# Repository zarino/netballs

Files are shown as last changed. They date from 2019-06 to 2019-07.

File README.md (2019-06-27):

# Interesting links about DMX

## General explainers

* [Element14 – DMX Explained](https://www.element14.com/community/groups/open-source-hardware/blog/2017/08/24/dmx-explained-dmx512-and-rs-485-protocol-detail-for-lighting-applications)
* [Sparkfun – Introduction to DMX](https://learn.sparkfun.com/tutorials/introduction-to-dmx/all)
* [Instructables – How to Use DMX512 / RDM With Raspberry Pi](https://www.instructables.com/id/How-to-Use-DMX512-RDM-With-Raspberry-Pi/)
  * …Uses a [Zihatec RS485 HAT for Raspberry Pi](https://www.hwhardsoft.de/english/projects/rs485-shield/)

## DMX interfaces

* [Bitwizard DMX interface board for Raspberry Pi](https://www.bitwizard.nl/shop/DMX-interface-for-Raspberry-pi) – with input and output
* Enttec seem to have cornered the market on USB-to-DMX adaptors – <https://www.enttec.co.uk/product/protocols-gb/dmx512-gb/open-dmx-usb/> – fairly expensive.
* Chap using a Raspberry Pi to control lights via a cheap clone of an Enttec USB-to-DMX interface – <https://www.youtube.com/watch?v=ch0sNUbO9lo>
* A completely DIY DMX interface, using an Arduino – <https://www.instructables.com/id/Build-Your-Own-DMX-Fixture-Arduino/>

## RS485 interfaces

* [Zihatec RS485 HAT for Raspberry Pi](https://www.hwhardsoft.de/english/projects/rs485-shield/)
  * …Which was used in [this Instructables guide](https://www.instructables.com/id/How-to-Use-DMX512-RDM-With-Raspberry-Pi/)
* <https://www.instructables.com/id/DMX-512-to-Serial-Adapter/>

## Raspberry Pi as DMX transmitter/controller ONLY

(Not quite what we’re after – we want Raspberry Pi to _receive_ DMX command over XLR cable.)

* QLC is Linux-based DMX controller software – <https://qlcplus.org/raspberry.html>
* “DiscoHAT” board sending DMX from a Raspberry Pi – <https://www.discohat.com/discohat/>
* Another example, using a Velleman USB-to-DMX interface [£61 on Amazon](https://www.amazon.co.uk/Velleman-K8062-Controlled-Interface-multicolored/dp/B000TA79UK) – <https://www.instructables.com/id/Raspberry-Pi-as-a-DMX-light-controller/>
* ["Tinkerkit" Arduino DMX Master Shield at RS Components](https://uk.rs-online.com/web/p/processor-microcontroller-development-kits/7798870/)

## ESP32 as DMX receiver

* [Sparkfun –  Using Artnet DMX and the ESP32 to Drive Pixels](https://learn.sparkfun.com/tutorials/using-artnet-dmx-and-the-esp32-to-drive-pixels)

## Arduino as DMX receiver

* https://www.maxpierson.me/2009/04/29/arduino-dmx-512-io-shield/

# I have no idea what this is all about, but it looks promising

* <https://sites.google.com/site/rpidmx512/>
   * <https://sites.google.com/site/rpidmx512/raspberry-pi-rdm-controller>
   * <https://sites.google.com/site/rpidmx512/raspberry-pi-rdm-responder>
* <https://github.com/vanvught/rpidmx512>

# DMX lighting control software for Mac

* <https://zarino.co.uk/post/udmx-mac/> – uDMX command line utility
* <https://lightkeyapp.com/en/> – free as long as you need fewer than 24 channels

# Raspberry Pi as Wifi access point and client

* <https://www.raspberrypi.org/documentation/configuration/wireless/access-point.md#internet-sharing>
* <https://lb.raspberrypi.org/forums/viewtopic.php?t=211542>
* <http://www.marrold.co.uk/2017/03/using-raspberry-pi-3-as-wifi-client-and.html>
* <https://raspberrypi.stackexchange.com/questions/67601/>

# MQTT

* <https://github.com/DoESLiverpool/somebody-should/wiki/MQTT-services>

# Power control for Raspberry Pi

* £6.50 OnOff SHIM – from [Pimoroni](https://shop.pimoroni.com/products/onoff-shim) or [The PiHut](https://thepihut.com/collections/raspberry-pi-hats/products/onoff-shim)
* £15 [Pi Supply Switch](https://uk.pi-supply.com/products/pi-supply-raspberry-pi-power-switch)

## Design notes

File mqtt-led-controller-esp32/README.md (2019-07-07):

# mqtt-led-controller-esp32

This MicroPython code tells the ESP32 how to:

1. Connect to the `netball-hub-wifi` network being broadcast by the [netball-hub](../netball-hub) Raspberry Pi.
2. Listen for MQTT messages on the `netball/…` topic, eg: `netball/red 255`
3. Translate those MQTT messages into control signals for the connected SK6812 LEDs.

## How to use this

### Install the serial driver onto your computer

Download and install the [CP210x USB-to-UART Bridge VCP serial driver](https://www.silabs.com/products/development-tools/software/usb-to-uart-bridge-vcp-drivers) if you don’t already have it.

If you’re on a Mac, you’ll need to “Allow” the extension in System Preferences – your Mac will show you how. You won’t need to restart your Mac after the installation.

### Test communication with the board

The Arduino IDE is a quick way to test you can communicate with your board. You will need to [follow the first section of this guide](https://randomnerdtutorials.com/installing-the-esp32-board-in-arduino-ide-mac-and-linux-instructions/) to install the ESP32 boards into the IDE’s Board Manager.

Zarino’s note: The first time I did this, I got an error when I tried to upload the “Wifi Scan” example code from the Arduino IDE to the board, for testing:

    serial.serialutil.SerialException: Could not configure port: (6, 'Device not configured’)

I read a quick fix is to hold down the BOOT button while the code was uploading, and that allowed the code to upload fine. But then I wasn’t getting any serial output. I tried pressing the BOOT and RST buttons, to no avail.

Unplugged and re-plugged the USB cable, and the ESP32 booted up and started writing serial to the Arduino Serial Monitor. Your mileage may vary.

### Flash the MicroPython firmware onto the board

You’ll probably also want to create a virtualenv to store the Python packages we’re about to install:

    cd mqtt-led-controller-esp32
    virtualenv .
    . bin/activate

Now install the Python packages:

    pip install -r requirements.txt

If you’re using a brand new EPS32, you’ll need to erase its flash memory:

    esptool.py --port /dev/tty.SLAB_USBtoUART erase_flash

Now, [download the latest MicroPython firmware binary for the ESP32](https://micropython.org/download#esp32), and flash it onto the board using this command (remembering to replace `/path/to/esp32-blah-blah.bin` with the path of the firmware binary you just downloaded):

    esptool.py --chip esp32 --port /dev/tty.SLAB_USBtoUART write_flash -z 0x1000 /path/to/esp32-blah-blah.bin

If you encounter any problems at this point, [check out the “Getting started with MicroPython on the ESP32“ tutorial here](https://docs.micropython.org/en/latest/esp32/tutorial/intro.html) for troubleshooting advice.

To test the MicroPython firmware has been correctly installed, open a terminal emulator session to the ESP32. On a Mac, you can do this using `screen`:

    screen /dev/tty.SLAB_USBtoUART 115200

Press the `Return` key a few times, and you should be given a command prompt like `>>>`. If you type some simple Python in here (like `1+1`) you should get an answer (`2`).

You can exit the `screen` session by pressing `ctrl`–`A` then `ctrl`–`\`.

### Upload the `minimalmdns.py` package onto the board

The ESP32 has a very simple filesystem. By default, the Python path expects local packages to be in the `/lib` directory. So we’ll need to create that directory, and then copy our `minimalmdns.py` package into it.

You do both of these things with the `ampy` command, installed as part of the `pip install -r requirements.txt` line you ran earlier.

First create the `/lib` directory on the ESP32:

    ampy --port /dev/tty.SLAB_USBtoUART mkdir /lib

Now copy `minimalmdns.py` into that `/lib` directory:

    ampy --port /dev/tty.SLAB_USBtoUART put vendor/minimalmdns.py /lib/minimalmdns.py

### Upload `main.py` onto the board

The ESP32 will run `/boot.py` on startup (if the file exists) and then `/main.py`.

To upload `main.py` to the ESP32:

    ampy --port /dev/tty.SLAB_USBtoUART put main.py

### Send test MQTT messages

Run commands like this to control the ESP32:

    mosquitto_pub --host netball-hub.local --topic netball/red -m 255

### Open a Python terminal on the ESP32

To open a terminal session on the ESP32:

    screen /dev/tty.SLAB_USBtoUART 115200

Press Enter or `Ctrl`-`C` to get to a Python REPL prompt.

Press `Ctrl`-`A` then `Ctrl`-`\`, then `Y` to exit.

## Useful links

* https://learn.sparkfun.com/tutorials/micropython-programming-tutorial-getting-started-with-the-esp32-thing/all
* https://github.com/dphans/micropython-ide-vscode

* https://github.com/DoESLiverpool/what-does-health-look-like/blob/master/mqtt_neopixel_visualiser/mqtt_neopixel_visualiser.ino
* https://github.com/goatchurchprime/jupyter_micropython_developer_notebooks/blob/master/projects/mqtt2drumneopixel_mdns.ipynb

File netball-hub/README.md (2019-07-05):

# netball-hub

Code relating to the setup of a Raspberry Pi as an MQTT broker and a DMX interface.

## Setting up Raspbian, wifi, and SSH access

Follow the instructions here to get the Pi into a suitable state for provisioning:

<https://zarino.co.uk/post/raspberry-pi-mac-setup/>

Change the Pi’s `hostname` to `netball-hub`, and set up password-less SSH login with `ssh-copy-id`, so that you can SSH right into the Pi with just:

    ssh pi@netball-hub.local

## Provisioning

Install Ansible on your main machine. For example, on a Mac:

    brew install ansible

Or on Ubuntu:

    sudo apt-get install ansible

Then run the provisioner in `ansible-provisioning`:

    cd ansible-provisioning
    ansible-playbook -i inventory.yml playbook.yml

_(Much of the MQTT provisioning has been adapted from instructions at <https://oneguyoneblog.com/2017/06/20/mosquitto-mqtt-node-red-raspberry-pi/>.)_

For now, you’ll need to install the RaspAP wifi access point stuff by hand. SSH into the Pi, then become root, and run the installer:

    ssh pi@netball-hub.local
    sudo su
    wget -q https://git.io/voEUQ -O /tmp/raspap && bash /tmp/raspap
    reboot

Now connect to the Pi’s wifi network:

    SSID      raspi-webgui
    Password  ChangeMe

The RaspAP admin interface should now be accessible at:

    URL       http://netball-hub.local/
    Username  admin
    Password  secret

Visit the [Configure hostspot](http://netball-hub.local/index.php?page=hostapd_conf) page and make the following changes:

* Basic->SSID: `netball-hub-wifi`
* Security->PSK: `bubblino`
* Advanced->Country Code: `United Kingdom`

Press the "Save settings" button, then cross your fingers. The `raspi-webgui` network should disappear, and a new `netball-hub-wifi` should replace it.

The Pi should have access to the wider internet (via its connection as a _client_ to the `DoESLiverpool` wifi network), but it doesn’t seem that devices _connected_ to the Pi’s `netball-hub-wifi` network will get the same internet connection. Annoying.

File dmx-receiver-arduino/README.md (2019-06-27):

# dmx-receiver-arduino

We have a cheap Arduino Uno clone, and a [Conceptinetics CTC-DRA-10-R2 DMX shield](https://www.tindie.com/products/Conceptinetics/dmx-shield-for-arduino-rdm-capable/).

The aim is to have the Uno read incoming DMX commands, on a configurable range of channels, and then send those commands to a connected Raspberry Pi, via [SoftwareSerial](https://www.arduino.cc/en/Reference/SoftwareSerial), since the Arduino can’t send serial comms over USB when the DMX shield is attached.

We’ll use a [YF08E voltage translator](http://www.datasheetcafe.com/yf08e-pdf-datasheet-30695/) to protect the Raspberry Pi’s 3.3V GPIO from the Arduino’s 5V output.

## How to set up the Arduino

You need to install the Conceptinetics DMX Library onto your computer before you can compile the code.

1. Download the DMX library as a `.zip` file from <http://sourceforge.net/projects/dmxlibraryforar>
2. Install the library using one of the methods described at <https://www.arduino.cc/en/Guide/Libraries>.

If the DMX shield is in place on the Arduino Uno, make sure its `EN` jumper is in the "off" position (shown as `EN` with a line above it, ie: "NOT EN") when you are uploading code to the Arduino. The DMX shield communicates with the Arduino over serial, so you must turn the shield off (by setting the `EN` jumper to "off") to re-enable normal serial communication between your computer and the Arduino.

Once you’ve uploaded the code to the Arduino, remember re-activate the shield by turning the `EN` jumper to the "on" position (shown as `EN` without a line above it).

## How to set up the Raspberry Pi

See [../serial-monitor-test-python](../serial-monitor-test-python).

## How to connect the Arduino and the Pi, via the voltage translator

<https://pinout.xyz> will come in useful for identifying the Pi GPIO pins.

* Arduino pin 10 -> Voltage translator B1
* Arduino pin 11 -> Voltage translator B2
* Arduino 5V -> Voltage translator VB
* Arduino GND -> Voltage translator GND

* Raspberry Pi USB -> Arduino USB (for power, and common ground)

* Pi pin 1 -> Voltage translator VA
* Pi pin 8 -> Voltage translator A1
* Pi pin 10 -> Voltage translator A2

* Voltage translator VA -> Voltage translator OE

## Useful links

DMX shield

* https://forum.arduino.cc/index.php?topic=458860.0 – Someone with our exact DMX Shield, discovering that it hogs the Serial RX/TX lines on the Arduino, meaning you can’t use USB Serial input/output when the shield is active.

I2C – Pi as master, Arduino as slave

* https://raspberrypi.stackexchange.com/questions/62206/sending-and-receiving-string-data-between-arduino-and-raspberry-pi-using-the-i2c – Example of using `RPi.GPIO` Python module, to send I2C commands from a Raspberry Pi master to an Arduino slave, and then the Arduino `Wire` library to receive those commands.

I2C – Pi as slave, Arduino as master

* https://raspberrypi.stackexchange.com/questions/76109/raspberry-as-an-i2c-slave – Raspberry Pi as I2C slave
* https://www.raspberrypi.org/forums/viewtopic.php?t=235740 – Raspberry Pi as I2C slave
* https://oroboto.net/2018/10/21/arduino-with-raspberry-pi-i2c-slave/ – Example of using `pigpio` C-library, via the Python bindings, to send I2C commands from an Arduino master to a Raspberry Pi slave.

I2C on a Pi in general

* https://github.com/joan2937/pigpio – `pigpio` C-library, includes Python bindings.
* https://learn.adafruit.com/adafruits-raspberry-pi-lesson-4-gpio-setup/configuring-i2c – Configuring I2C on a Raspberry Pi.
* https://pinout.xyz/pinout/i2c – Pinout diagram showing location of I2C pins on Raspberry Pi.
* https://learn.sparkfun.com/tutorials/raspberry-pi-spi-and-i2c-tutorial/all – Nice clear example of using I2C on a Raspberry Pi (using `smbus` Python library).

I2C on an Arduino in general

* https://github.com/mcauser/i2cdetect – Arduino version of the Pi’s `i2cdetect` utility program, useful for showing I2C addresses of devices connected to the Arduino.

3.3V Pi GPIO vs 5V Arduino GPIO

* https://raspberrypi.stackexchange.com/questions/95430/5v-3-3v-sensors-confusion – Info about the danger of sending 5V signals to the Raspberry Pi’s 3V GPIO.
* https://www.raspberrypi-spy.co.uk/2018/09/using-a-level-shifter-with-the-raspberry-pi-gpio/ – voltage level shifting.

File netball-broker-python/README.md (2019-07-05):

# netball-broker-python

`broker.py` is the script that will eventually run on the Rasbperry Pi, reading (software) serial data from the connected Arduino Uno, and publishing them to its MQTT server.

`serial-debug.py` is a handy command line script for testing the Pi’s software serial connection – it just prints out any data received on the specified serial port.

## Running broker.py as a systemd background process, on boot

Git clone this repo onto the Raspberry Pi, and make sure you’ve installed the Python dependencies:

    cd /home/pi
    git clone https://github.com/zarino/netballs.git
    cd netballs/netball-broker-python/
    pip install -r requirements.txt

Copy the `netball-broker.service` file to the systemd directory:

    sudo cp /home/pi/netballs/netball-broker-python/netball-broker.service /lib/systemd/system/netball-broker.service
    sudo chmod 644 /lib/systemd/system/netball-broker.service

Note: If you’ve checked out the Git repo somewhere _other_ than `/home/pi/netballs` then you’ll need to amend the `ExecStart` line inside `netball-broker.service` to include the correct path to `broker.py`.

Once the `netball-broker.service` file has been copied, you can tell systemd to load it:

    sudo systemctl daemon-reload
    sudo systemctl enable netball-broker

Systemd will start the service at the next boot.

If you want to start the service _right now_, you can:

    sudo systemctl start netball-broker

Other systemd commands work as you’d expect:

    systemctl status netball-broker
    sudo systemctl stop netball-broker

And if you want to test it out by rebooting the Pi:

    sudo reboot

## Tips for debugging

You can publish and monitor MQTT messages using the [mosquitto command line programs](https://mosquitto.org/download/). This comes in handy when you want to send a test message, or you want to see which messages are already being sent.

On a Mac, you can get it via Homebrew:

    brew install mosquitto

Then, to publish a message:

    mosquitto_pub --host netball-hub.local --topic netball/red -m 255

And to monitor all messages:

    mosquitto_sub -v --host netball-hub.local --topic '#'

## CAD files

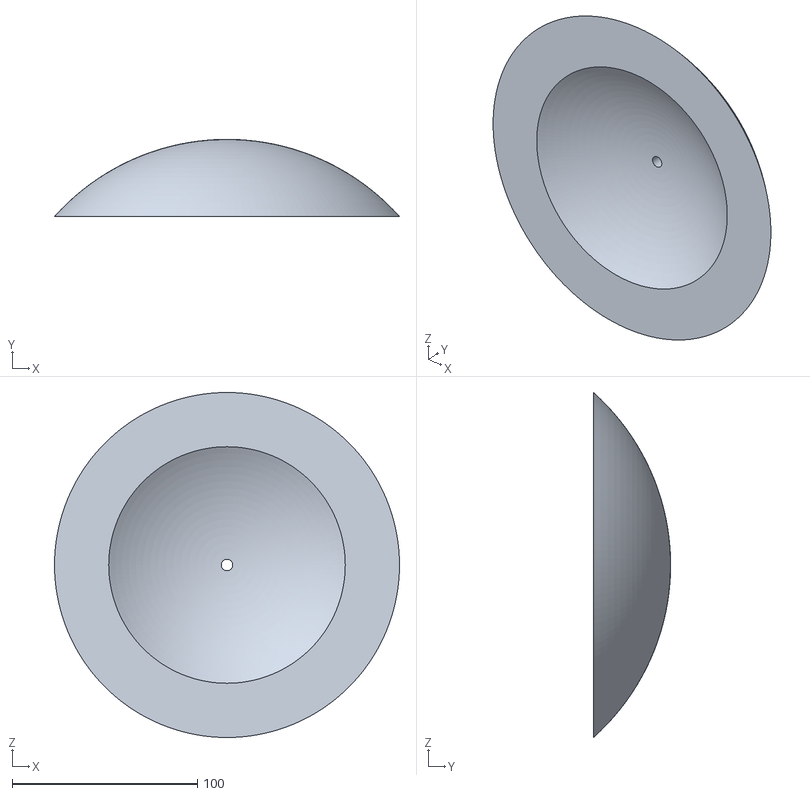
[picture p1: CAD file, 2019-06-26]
netball-3dp-files/netballTop.stl
186.3 x 41.6 x 186.3

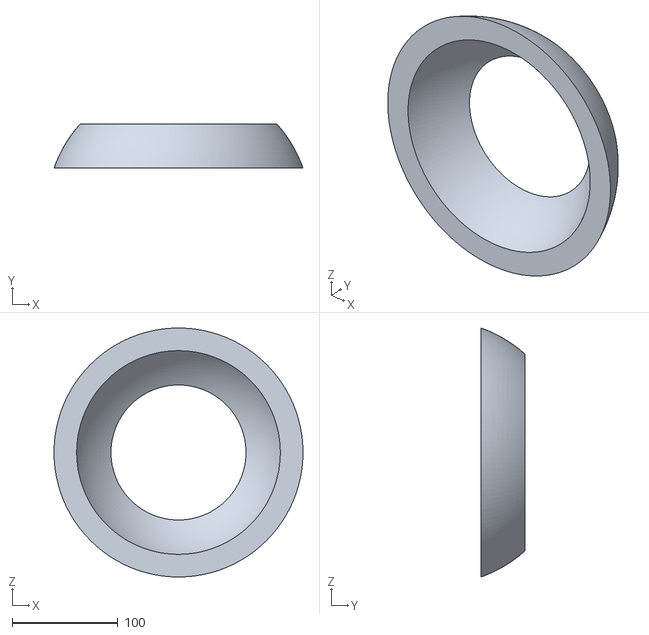
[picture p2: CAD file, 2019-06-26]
netball-3dp-files/netball2ndLayer.stl
235.7 x 41.7 x 235.7

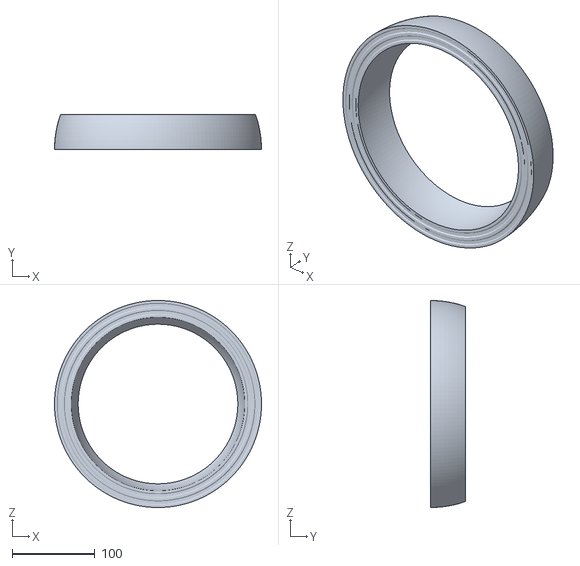
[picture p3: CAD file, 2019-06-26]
netball-3dp-files/netball3rdLayer.stl
250.0 x 41.7 x 250.0

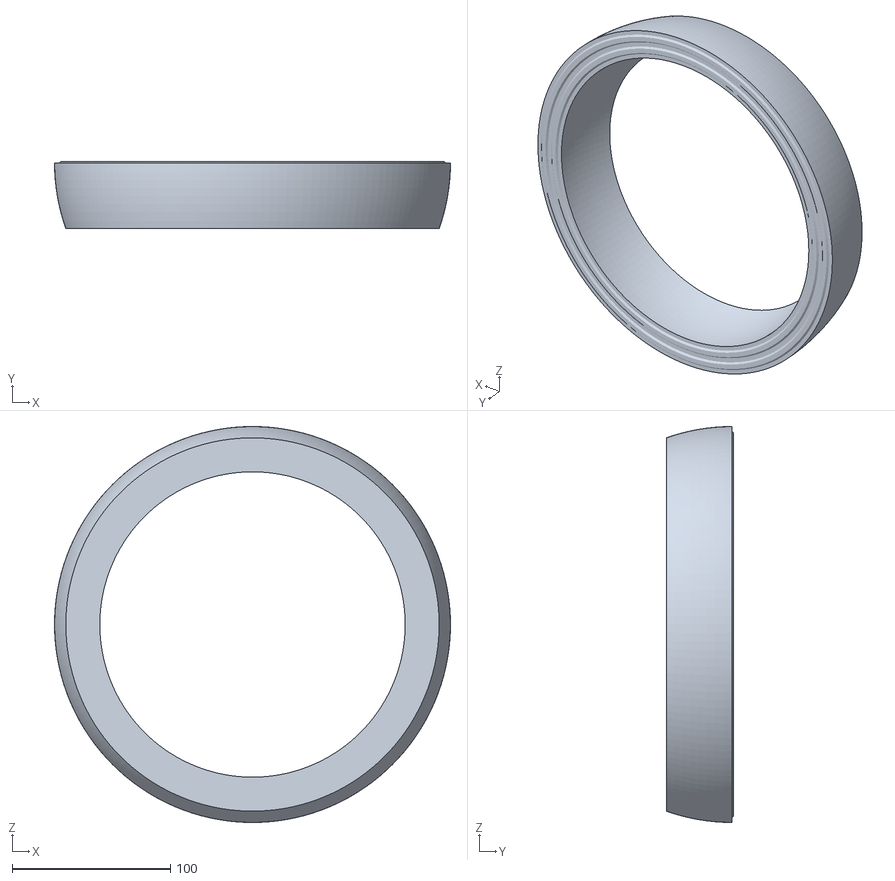
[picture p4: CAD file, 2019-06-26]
netball-3dp-files/netball4thLayer.stl
250.0 x 42.6 x 250.0

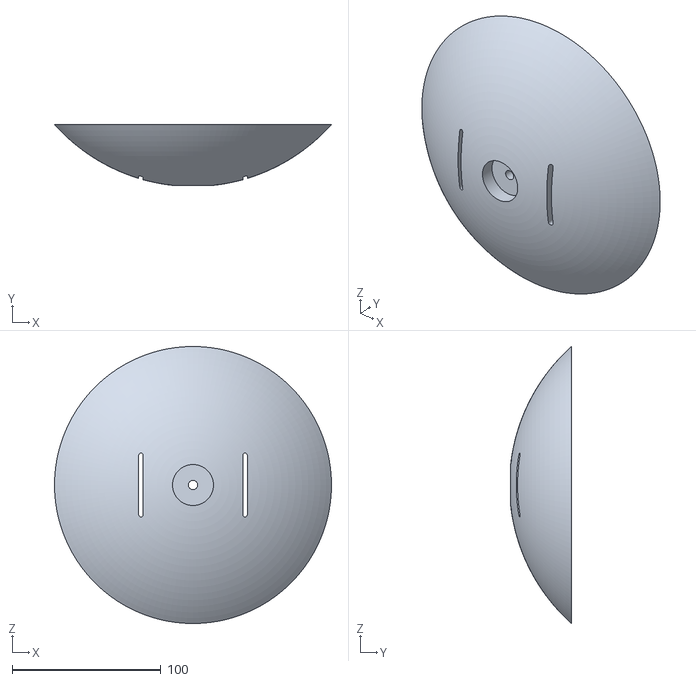
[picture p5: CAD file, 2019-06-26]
netball-3dp-files/netballBase.stl
186.3 x 40.9 x 186.3

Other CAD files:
netball-3dp-files/netball5thLayer.stl

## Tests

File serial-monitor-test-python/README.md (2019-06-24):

# serial-monitor-test-python

Quick Python script for reading and printing serial input.

Useful when combined with an Arduino running the [serial-print-test-arduino](../serial-print-test-arduino) program.

## How to use this

You’ll probably want to create a virtualenv to store the Python library we’re about to install:

    cd serial-monitor-test
    virtualenv .
    . bin/activate

Now install the [`pyserial`](https://pythonhosted.org/pyserial/index.html) library:

    pip install -r requirements.txt

And finally run the script:

    ./monitor.py

Exit the program by typing `ctrl`-`C`.

The script assumes a serial port path of `/dev/ttyUSB0`. If yours is different, supply it as an argument:

    ./monitor.py -p /dev/tty.wchusbserial1410

You can see all options by adding `--help`:

    ./monitor.py --help

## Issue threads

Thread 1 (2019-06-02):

Power

jackie1050, 2019-06-02:
# Powering the ESP32

9v battery
https://docs.zerynth.com/latest/official/board.zerynth.doit_esp32/docs/index.html#power
> Power to the DOIT Esp32 DevKit v1 is supplied via the on-board USB Micro B connector or directly via the “VIN” pin. The power source is selected automatically.
>
> The device can operate on an external supply of 6 to 20 volts. If using more than 12V, the voltage regulator may overheat and damage the device. The recommended range is 7 to 12 volts.

jackie1050, 2019-06-02:
SK6812:
https://cellpacksolutions.co.uk/products/batteries/gp-batteries-gp410lah-18650-rechargeable-battery/
GP Batteries GP410LAH 18650 Rechargeable Battery
Need a battery charger: https://cellpacksolutions.co.uk/products/product-category/battery-chargers/nimh-nicd/
Something to hold 4 in series (3d printed or bought - not a standard AA size)
Switch to disconnect from circuit

zarino, 2019-06-15:
John C has offered us twenty 3.7V 4000mAh Li-ion 18650 batteries.

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

Despite these being 3.7V (rather than 5V) we’ve had one driving a strand test on 60 SK6812 LEDs, at full brightness, and it’s been working fine for 45 minutes and countring.

zarino, 2019-07-28:
We did this with John C’s 3.7V 4000mAh Li-ion 18650 batteries.

It wasn’t perfect though (the low voltage caused random flickering) so maybe in future we’ll want to consider proper 5V alternatives. Potentially two 3.7V 18650s, in series, with a step down converter.

Closed 2019-07-28.

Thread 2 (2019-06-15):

Get Raspberry Pi to read PWM output from DMX Decoder

zarino, 2019-06-15:
Our DMX decoder outputs PWM on 4 channels, corresponding to the 0–255 data it receives on the 4 incoming DMX channels.

We need to read the PWM output from a Raspberry Pi, so that it can forward the message on to the ESP32s in the balls via MQTT.

The DMX decoder runs on 12V – can the Raspberry Pi GPIO withstand that? Or will we need to step it down somehow?

zarino, 2019-06-25:
We’re now going to do this via an Arduino Uno. So the flow is something like:

DMX input -> [DMX shield](https://www.tindie.com/products/Conceptinetics/dmx-shield-for-arduino-rdm-capable/) -> Arduino Uno -> (I2C) -> Raspberry Pi

Outstanding questions right now:

* Which should be the I2C master – the Arduino or the Pi?
* Will we need the I2C comms to go over a voltage translator, to shift the Arduino’s 5V down to the Pi’s 3.3V?
* What’s the simplest way of powering the two devices? (Could maybe power the Arduino from one of the Pi’s USB ports?)

paulgeering, 2019-07-03:
The Arduino Uno receiving DMX and sending out via serial, is showing some unwanted glitching/instability.

**DMX Masters tested:**
Mac + uDMX cable: **Glitchy**
Arduino Uno + [Conceptinetics library](http://sourceforge.net/projects/dmxlibraryforar): **Glitchy**
Cheap RGB Disco light DMX output: **Rock Solid**
[Stran 100 Professional Lighting desk](https://www.strandlighting.com/global/products/100-plus): **Glitchy**

More investigation needed, but the current solution probably shouldn't be used as the core of our system till we know what's up. (I'll bring my work's oscilloscope to MakerNight)

It only needs to work with the Lighting desk that will be used for the event, (Although having a test setup is fairly essential for us to be confident of the solution we develop), so any details we can get on that would be great.

paulgeering, 2019-07-03:
[DMXSerial](http://www.mathertel.de/Arduino/DMXSerial.aspx) might be worth another look, as an alternative DMX receiving library.

paulgeering, 2019-07-03:
> DMXSerial might be worth another look, as an alternative DMX receiving library.

I ported our test code over to using the DMX Serial Library.

Once again, the output from the DMX Disco Light was read fine, but the DMX from the lighting desk was not being received correctly.

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

If the receiving was correct, we should see:
10 20 40 80 0
10 20 40 80 0
10 20 40 80 0
10 20 40 80 0
10 20 40 80 0
10 20 40 80 0
10 20 40 80 0
10 20 40 80 0
10 20 40 80 0

paulgeering, 2019-07-04:
If we decide to go back to the DMX to PWM hardware decoder, then we have a few options for reading the PWM into the Raspberry Pi

We could use an Arduino to read the PWM and send values over serial to the Pi
[Overview of PWM decoding](https://www.benripley.com/diy/arduino/three-ways-to-read-a-pwm-signal-with-arduino/)
[Simple method if we don't need many updates per second](https://www.arduino.cc/reference/en/language/functions/advanced-io/pulsein/)
[Some other library.](https://github.com/xkam1x/Arduino-PWM-Reader)

Or we could attempt PWM decoding on the raspberry Pi itself
[PWM decoding in C on RPi](https://raspberrypi.stackexchange.com/a/61452)
[PWM decoding in Python on RPi](https://raspberrypi.stackexchange.com/a/68824)

Each of these would still likely require some level conversion given the output of the decoder box was in the region of 12-15 volts.

paulgeering, 2019-07-06:
DMX512 is a very a standard that allows a very broad range of timings.

Investigations on Thursday showed the Arduino DMX decoding libraries could cope with DMX that had its slots and frames well spaced out.
This seemed to give the Arduino time to buffer and decode the signal.

The disco light had spaced out signals (and also a non-compliant DMX Break period)
The DMX simple library was sending bursts of tightly packed slots
The uDMX ,and the presumably the lighting desk, were sending the DMX slots and frames with little to no spacing between them.

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

zarino, 2019-07-28:
The legendary @paulgeering has submitted a pull request to fix these timing issues, at the level of the Arduino, rather than the Raspberry Pi, which works great, but just needs to be reviewed and merged: https://github.com/zarino/netballs/pull/8

Closing this ticket now, though, since the code we wrote for the Pi works fine.

Closed 2019-07-28.

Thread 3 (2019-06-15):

Get Anyma uDMX USB-to-DMX adaptor working with controller software, for testing

zarino, 2019-06-15:
I’ve tried plugging the Anyma uDMX into my Mac, and using [QLC+](https://qlcplus.org/) to control the lights on our DMX Decoder, but even after reducing QLC’s uDMX frequency down from 30Hz to 16Hz ([as suggested here](https://www.qlcplus.org/forum/viewtopic.php?t=9108)), the signals seem to stop after 5 seconds of activity.

The [Anyma website](http://www.anyma.ch/research/udmx/) says you can control the uDMX adaptor directly from the command line, via a uDMX binary (eg: `./uDMX 1 255 255 255 255`) but I tried downloading their Mac binary, and it refused to run, with a `Bad CPU type` exception – is it possible that the binaries on the website we compiled for… PowerPC?? Surely not.

Maybe another DMX controller software might work. The Anyma website says the uDMX is compatible with [OLA](https://www.openlighting.org/ola/), so maybe it might also be compatible with a whole bunch of other pieces of software.

zarino, 2019-06-25:
This has been done. See https://zarino.co.uk/post/udmx-mac/ for details on how to send simple test commands from the command line on a Mac.

Closed 2019-06-25.

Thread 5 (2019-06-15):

Program the ESP32s to receive colours over MQTT, and control the SK6812 LEDs

zarino, 2019-06-15:

zarino, 2019-07-28:
This worked fine, although the 3.7V power supply resulted in a small amount of random colour "flickering" in the LEDs – we _think_ because they’re expecting 5V.

Closed 2019-07-28.

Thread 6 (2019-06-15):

3D print battery holders for inside the balls

zarino, 2019-06-15:
Spun out from #1.

I think we want four of the 3.7V 4000mAh Li-ion 18650 batteries per ball. So maybe we should 3D print a 4-cell holder, rather than 4 separate ones?

Need to consider whether we want to power the ESP32s off the same 4 batteries, or off a 5th battery, or off something else entirely.

jackie1050, 2019-07-14:
We bought standard battery holders to save time

Closed 2019-07-14.

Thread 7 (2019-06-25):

Program the Pi to send/expose colours to the ESP32s over MQTT

zarino, 2019-06-25:
Once the Raspberry Pi receives the DMX commands (#2) it will need to make these available to the ESP32s.

zarino, 2019-07-28:
We did this! It was awesome!

Closed 2019-07-28.

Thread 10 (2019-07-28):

Enable the balls to be powered off a mains power supply

zarino, 2019-07-28:
Sometimes we’ll want to run the balls for extended periods of time, in a fixed location. It’d be good to have them run off a 5V power brick.

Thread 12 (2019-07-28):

Laser cut a storage box that holds 2 balls and their controller

zarino, 2019-07-28:
The box should be easy to carry and fully opaque (to prevent the PLA from degrading in sunlight).

It’d be nice if the box doubled up as a display stand for one or both balls, when operating in mains power mode (#10).

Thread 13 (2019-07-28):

Investigate controlling the balls over Art-Net

zarino, 2019-07-28:
* https://learn.sparkfun.com/tutorials/using-artnet-dmx-and-the-esp32-to-drive-pixels
* https://sites.google.com/site/artnetcontroller

The ESP32s could receive Art-Net commands directly, rather than requiring a central controller.

jackie1050, 2019-09-02:
A few weeks ago I uploaded the Sparkfun example to an ESP32 and attached a short neopixel strip. I haven't tried Art-Net from a PC, but was able to control lights via an Android app, Art-Net Controller LITE.

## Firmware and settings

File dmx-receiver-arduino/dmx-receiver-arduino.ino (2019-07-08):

#include <Rdm_Defines.h>
#include <Rdm_Uid.h>
#include <Conceptinetics.h>

#include <SoftwareSerial.h>

// Number of channels to be monitored by the dmx_slave object,
// starting with the start address.
#define DMX_SLAVE_CHANNELS 5

// The first channel to monitor.
// As it happens, 1 is the default for .setStartAddress() anyway.
#define DMX_START_ADDRESS 1

// We're using Software Serial, because the normal serial pins
// and USB serial comms are being used by the DMX shield.
#define SERIAL_RX_PIN 10
#define SERIAL_TX_PIN 11
#define SERIAL_BAUD_RATE 9600

DMX_Slave dmx_slave(DMX_SLAVE_CHANNELS);

SoftwareSerial software_serial(SERIAL_RX_PIN, SERIAL_TX_PIN);

// We think there's some weird timing issue if you try to
// software_serial.print() inside the onReceiveComplete callback.
// So here we set up an array to batch up values, so we can print
// a bunch of them at once, outside the getChannelValue() loop.
uint8_t latestValues[DMX_SLAVE_CHANNELS];

void setup() {
    // Enable DMX slave interface and start recording DMX data.
    dmx_slave.enable();

    dmx_slave.setStartAddress(DMX_START_ADDRESS);

    // Tell DMX_Slave to call this callback when it receives a full frame.
    dmx_slave.onReceiveComplete(onFrameReceiveComplete);

    software_serial.begin(SERIAL_BAUD_RATE);
}

void loop() {
    for (int i=0; i<DMX_SLAVE_CHANNELS; i++) {
        software_serial.print( latestValues[i] );
        software_serial.print( " " );
    }
    software_serial.println();
    delay(50);
}

void onFrameReceiveComplete (unsigned short channelsReceived) {
    // Wait until we've been notified about a frame with all the required channels.
    if ( channelsReceived == DMX_SLAVE_CHANNELS) {
        // Store the current value of each channel, so the main loop()
        // can access the latest values when it comes time to print.
        for (int i=DMX_START_ADDRESS; i<DMX_START_ADDRESS+DMX_SLAVE_CHANNELS; i++) {
            latestValues[i-DMX_START_ADDRESS] = dmx_slave.getChannelValue(i);
        }
    }
}

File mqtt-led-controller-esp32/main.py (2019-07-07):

import machine
import neopixel
import network
import time
import random

from minimalmdns import mdnshostnametoipnumber
from umqtt.robust import MQTTClient


number_of_leds = 60

wifi_ssid = 'netball-hub-wifi'
wifi_password = 'bubblino'
mqtt_broker_hostname = 'netball-hub.local'
mqtt_client_name = "{}{}".format('netball-esp32-', machine.unique_id())
mqtt_topic_base = "netball/"

channels = [
    "red",
    "green",
    "blue",
    "white",
    "sparkle",
]

state = {
    "red": 0,
    "green": 0,
    "blue": 0,
    "white": 0,
    "sparkle": 0,
}


# Set up neopixel string.
np = neopixel.NeoPixel(
    machine.Pin(4),
    number_of_leds,
    bpp=4
)


# The callback that handles MQTT messages.
def mqtt_message_callback(topic, msg):
    topic = topic.decode('utf-8')
    msg = msg.decode('utf-8').strip()
    print("MQTT message:", topic, msg)

    if topic.startswith(mqtt_topic_base):
        # Remove the mqtt_topic_base from the start of the topic,
        # leaving only the subtopic (eg: "red", "sparkle", or "all")
        channel = topic[len(mqtt_topic_base):]

        # A single channel/colour pair.
        if channel in channels:
            state[channel] = int(msg)

        # A request to change all channels at once.
        elif channel == 'all':
            values = msg.split()
            output = [0, 0, 0, 0, 0]
            # If only one colour provided, repeat that across red, green,
            # and blue channels (leaving white and sparkle empty).
            if len(values) == 1:
                values = values * 3
            for i, value in enumerate(values):
                output[i] = int(value)
            for i, key in enumerate(channels):
                state[key] = output[i]


# Magic.
def update_leds():
    for x in range(0, number_of_leds):
        if sparkling(state["sparkle"]):
            np[x] = (
                255,
                255,
                255,
                255,
            )
        else:
            np[x] = (
                state["red"],
                state["green"],
                state["blue"],
                state["white"],
            )

    np.write()


# Less or more likely to return True, based on the sparkle_chance.
# sparkle_chance of 0 means 0% chance of returning True.
# sparkle_chance of 255 means 100% chance of returning True.
def sparkling(sparkle_chance):
    return sparkle_chance > 0 and sparkle_chance >= random.randint(1, 256)


# Set all LEDs to the same colour. Useful for debugging.
def fill_all_leds(r, g, b, w):
    for x in range(0, number_of_leds):
        np[x] = (r, g, b, w)
    np.write()


# Clear LEDs before we start.
fill_all_leds(0, 0, 0, 0)


# Wait a little bit before we turn on wifi.
time.sleep(1.5)
wifi = network.WLAN(network.STA_IF)
wifi.active(True)


print("Connecting to", wifi_ssid)
fill_all_leds(0, 0, 255, 0) # blue


# Connect to the specified wifi network.
wifi.connect(wifi_ssid, wifi_password)
while not wifi.isconnected():
    time.sleep(0.1)


print("Connected to", wifi_ssid)
fill_all_leds(0, 255, 0, 0) # green
time.sleep(1)


print("Connecting to MQTT broker")
fill_all_leds(255, 150, 0, 0) # yellow
time.sleep(2)


# Find out the IP address of the MQTT broker.
if mqtt_broker_hostname[-6:] == ".local":
    print("Looking up MQTT broker IP address")
    mqtt_broker_ip = mdnshostnametoipnumber(wifi, mqtt_broker_hostname)
    print("mDNS completed:", mqtt_broker_hostname, "=", mqtt_broker_ip)
else:
    mqtt_broker_ip = mqtt_broker_hostname


# Connect to MQTT broker.
client = MQTTClient(mqtt_client_name, mqtt_broker_ip, 1883)
print("Connecting to MQTT broker", mqtt_broker_ip, "as client", mqtt_client_name)
for i in range(100):
    try:
        client.connect()
        break
    except OSError as e:
        print(e)
        fill_all_leds(255, 0, 0, 0)


print("Connected to MQTT broker", mqtt_broker_ip)
for i in range(0, 3):
    fill_all_leds(0, 0, 0, 0)
    time.sleep(0.3)
    fill_all_leds(0, 0, 0, 255)
    time.sleep(0.3)


# Reset LEDs again, ready for normal operation.
fill_all_leds(0, 0, 0, 0)


# Listen for MQTT messages.
client.set_callback(mqtt_message_callback)
client.subscribe( "{}#".format(mqtt_topic_base) )


while True:
    client.check_msg()
    update_leds()
    time.sleep_ms(25)

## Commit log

2019-06-23 Begin instructions for setting up the Raspberry Pi DMX hub
2019-06-23 Update README.md
    Added Arduino as a DMX receiver
2019-06-24 Test serial scripts for Arduino (C) and Raspberry Pi (Python)
2019-06-25 Example code for Arduino receiving DMX data
2019-06-26 Added draft stl files for netball - Onshape document here: https://cad.onshape.com/documents/758fec708367e0a22e536eb7/w/43407b539f7507c1da4ac73e/e/d23907639e521f144b84850b
    [netball2ndLayer.stl, netball3rdLayer.stl, netball4thLayer.stl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]
2019-06-27 Document how to connect arduino and pi for software serial
2019-06-27 DMX receiver arduino now sends space-separated values over software serial
2019-06-27 autogenerated vscode helper files for dmx-receiver-arduino
2019-06-28 Example of reading DIP switch values on Arduino
2019-07-03 Setup instructions for ESP32
2019-07-03 Manual neopixel control in mqtt-led-controller-esp32
2019-07-05 [WIP] Callback-based DMX receiver / serial printer
2019-07-05 Python code for Raspberry Pi serial->MQTT messaging
2019-07-05 Improved Arduino software serial test
2019-07-05 Fix --help bug in netball-broker-python/broker.py
    [broker.py]
2019-07-05 Fix dictionary iteration bug in broker.py
    [broker.py]
2019-07-05 Verbose option for broker.py
    To print output as well as sending over MQTT.
    [broker.py]
2019-07-05 Remove Client AP Mode from README
    This just doesn’t work. Attempting to have the Pi both broadcast a
    wifi network and be a client on an existing one (even if it’s not
    *actually* doing both) makes the Pi’s wifi SSID invisible to the ESP32.
2019-07-06 ESP32 MQTT lighting
2019-07-07 Much better diagnostics for MQTT ESP32 receiver
2019-07-07 Send decoded DMX from Arduino at most every 200 milliseconds
    The ESP32 was drowing in MQTT messages, because the Arduino and Pi were
    just publishing the DMX values as quickly as they came in.
    Now, the Arduino records the latest DMX value for each channel, updated
    every time a full DMX frame is received, and only publishes the latest
    values every 500 milliseconds.
    This means the ESP32 is no longer struggling to keep up with the colour
    changes, but it drastically increases the chance of erroneous DMX values
    slipping in, if/when the Arduino DMX shield misreads the DMX timings.
    [dmx-receiver-arduino.ino]
2019-07-08 Broker.py: Send messages as netball/all, rather than individual colours
    Also, only send new MQTT messages if the values have actually changed.
    Both of these changes should dramatically reduce the amount of MQTT
    network traffic, and make the ESP32 more responsive.
    [broker.py]
2019-07-08 Send decoded DMX from Arduino every 50ms, rather than 200ms
    Now that the Raspberry Pi is generating less MQTT chatter, we can up
    the frequency of the decoded DMX dumps from the Arduino.
    This helps the lights feel a bit more responsive, but still doesn’t
    solve the problem of weird flashing if/when the DMX shield misreads
    the DMX slots (sporadically putting values into the wrong channels).
    [dmx-receiver-arduino.ino]
2019-07-08 Allow manual overrides in broker.py via GPIO pins
    [broker.py]
